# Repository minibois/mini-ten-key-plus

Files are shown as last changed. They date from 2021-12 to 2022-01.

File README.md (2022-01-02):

# mini-ten-key-plus
## Repository for the mini Ten Key Plus, a Pro Micro based numpad/macropad PCB, suitable for up to 25 MX(-like) keyswitches and a (tactile) rotary encoder.
It is recommended to download the latest release of this project: https://github.com/minibois/ten-key-plus/releases

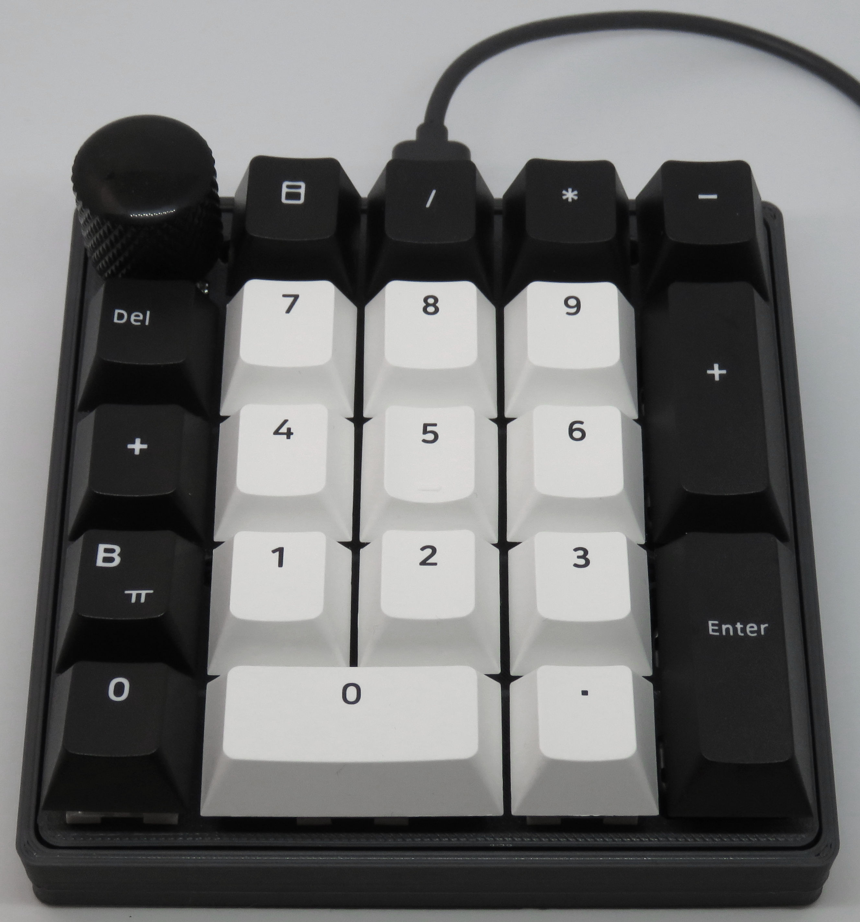
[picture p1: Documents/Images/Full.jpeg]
mini-Ten-Key-Plus-Built

 This PCB can be used using a 3D printed plate and case, also provided in this repository

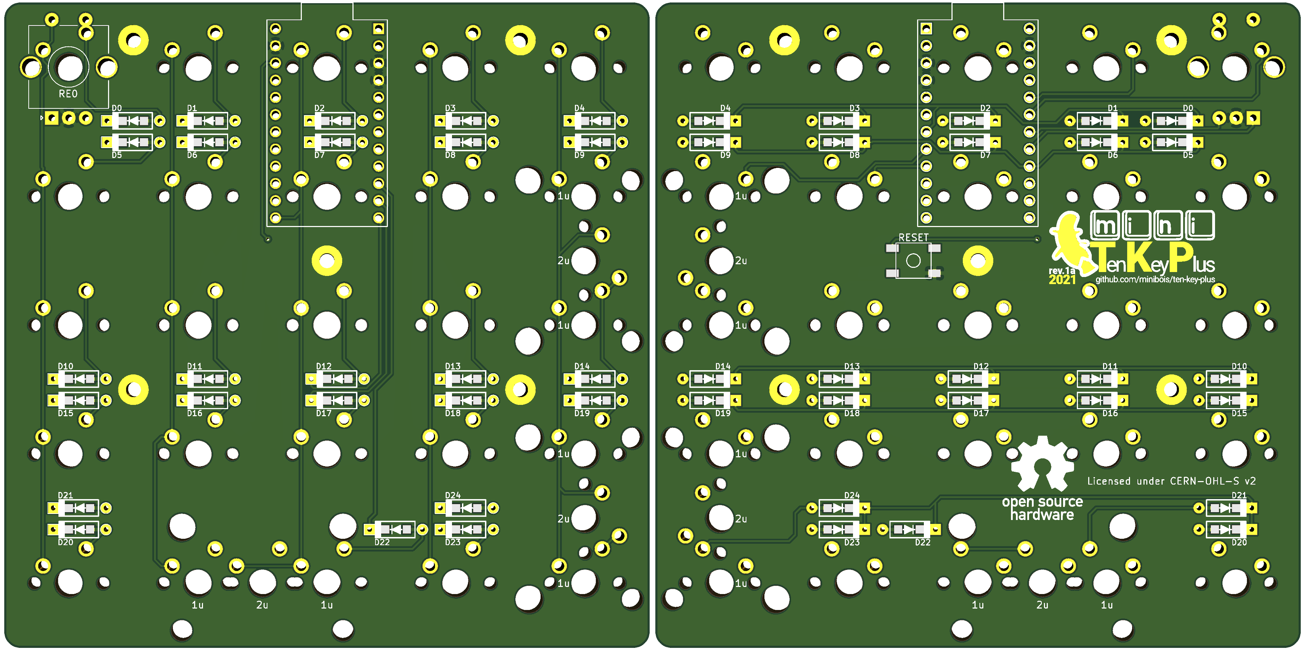
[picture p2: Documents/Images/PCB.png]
mini-Ten-Key-Plus-PCB-Render

 _Render of the front and back of the PCB respectively_

 << [License](https://github.com/minibois/ten-key-plus/tree/master/LICENSE) || [Assembly Guide](https://github.com/minibois/ten-key-plus/blob/master/Documents/Assembly%20Guide.pdf) || BOM ([Octoparts](https://octopart.com/bom-tool/pvFPXgm8)) / ([.txt](https://github.com/minibois/ten-key-plus/blob/master/Documents/BOM.txt)) / ([.xlsx](https://github.com/minibois/ten-key-plus/blob/master/Documents/BOM.xlsx)) || [Supported layouts](https://raw.githubusercontent.com/minibois/ten-key-plus/master/Documents/Layouts/layouts.png) || Schematic ([.pdf](https://github.com/minibois/ten-key-plus/blob/master/Documents/Schematic.pdf)) / ([.sch](https://github.com/minibois/ten-key-plus/blob/master/mini-ten-key-plus.sch)) || PCB ([.pdf](https://github.com/minibois/ten-key-plus/blob/master/Documents/PCB.pdf)) / ([.kicad_pcb](https://github.com/minibois/ten-key-plus/blob/master/mini-ten-key-plus.kicad_pcb)) >>

 The PCB and schematic are licensed under CERN-OHL-S v2, full license details can be found here: https://github.com/minibois/ten-key-plus/tree/master/LICENSE/LICENSE.txt.

## Libraries used in this project (most of them adapted to this project):
 * That-Canadian's KiCad_labs (for the D-SOD123_axial-dual): https://github.com/That-Canadian/KiCad_Libs
 * Type-C.Pretty: https://github.com/ai03-2725/Type-C.pretty
 * MX_Alps_Hybrid: https://github.com/ai03-2725/MX_Alps_Hybrid
 * random-keyboard-parts (for a reset switch): https://github.com/ai03-2725/random-keyboard-parts.pretty

### This PCB file and schematic is provided - as per CERN-OHL-S v2 section 6 - _without any warranty_ (implied or otherwise). https://ohwr.org/cern_ohl_s_v2.pdf
### The assembly guide is provided under the CC BY-SA 4.0, without any warranty (implied or otherwise): https://creativecommons.org/licenses/by-sa/4.0/legalcode

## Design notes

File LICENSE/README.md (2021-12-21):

# Copyright minibois 2021.

This source describes Open Hardware and is licensed under the CERN-OHL-S v2.
You may redistribute and modify this source and make products using it under the terms of the CERN-OHL-S v2 (https://ohwr.org/cern_ohl_s_v2.txt).
This source is distributed WITHOUT ANY EXPRESS OR IMPLIED WARRANTY, INCLUDING OF MERCHANTABILITY, SATISFACTORY QUALITY AND FITNESS FOR A PARTICULAR PURPOSE.
Please see the CERN-OHL-S v2 for applicable conditions.

As per CERN-OHL-S v2 section 4, should you produce hardware based on this source, you must where practicable maintain the Source Location visible on the keypad PCB or on other products you make using this source.
Source location: https://github.com/minibois/ten-key-plus
When changes have been made, please update ../Documents/CHANGES.txt accordingly.

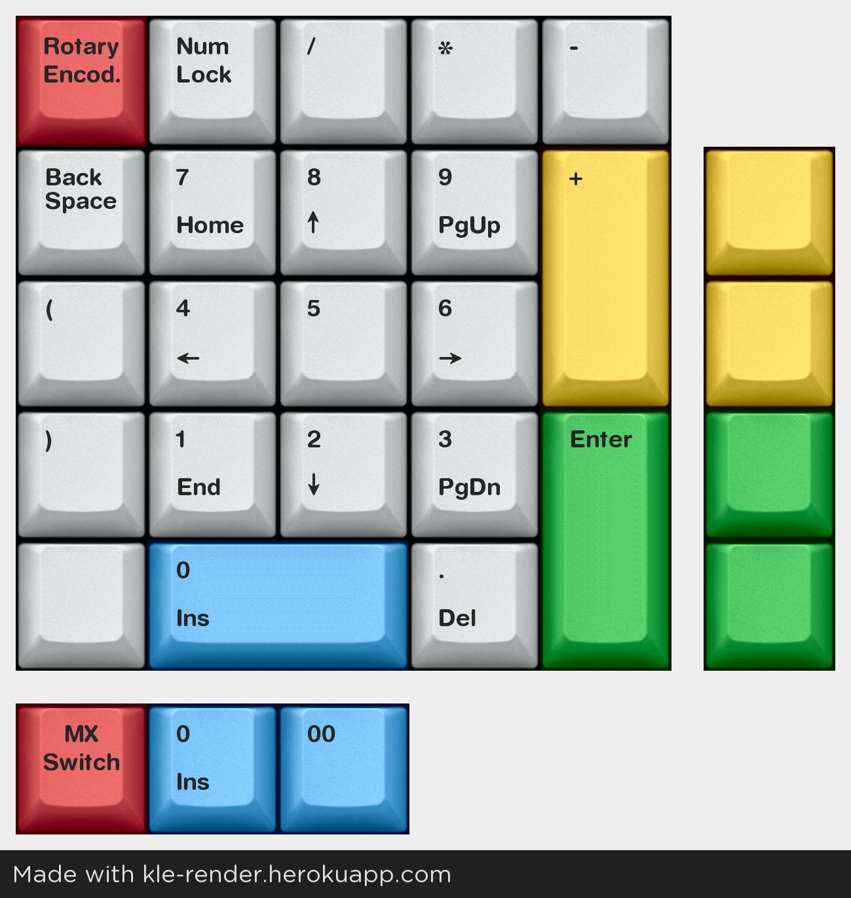
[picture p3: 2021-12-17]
Documents/Layouts/layouts.png

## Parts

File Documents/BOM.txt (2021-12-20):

Qty	Product			Description	Schematic	Notes
1	mini_Ten_Key_Plus PCB	PCB		N/A		To be purchased from your preffered PCB manufacturer
1	Arduino Pro Micro	Microcontroller	U0		Pro Micro or equivalent (i.e. Elite-C)
1	MCU Hotswap sockets	Microcontroller	N/A		(Optional) Hotswap socket for microcontroller, to allow for the removal of the MCU.
22-25	1N4148			THT Diode	D0-D24		Either this or 1N4148W
22-25	1N4148W			SMD Diode	D0-D24		Either this or 1N4148
22-25	MX Switches				MX0-MX24	MX (or MX-like) switches
1	RS187R05A2DSMTRT	Reset Switch	SW0
1	ALP-ENC-IND-000		Rotary Encoder	RE0		(Optional)
1 	Stabilizers						(Optional) Stabilizers for 2u keys
1	Lubricant						(Optional) to make the stabilizers feel better
22-25	Keycaps							A set appropriate for the chosen layout
1	USB type C cable					USB 2.0 or better
	3D printed case 					Refer to the assembly guide for additional information
	3D printed plate					Refer to the assembly guide for additional information
5	Heat Insert						M2, 3mm diameter, 3mm length heat inserts
5	Standoffs						M2, 3mm height
5	Screw							M2, 4mm height
2	Case feet						(Optional) feet to prop up the case
	Assembly tools/supplies					Refer to the assembly guide for a list of tools and supplies needed

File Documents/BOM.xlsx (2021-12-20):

Qty | Product | Description | Schematic | Notes
1 | mini_Ten_Key_Plus PCB | PCB | N/A | To be purchased from your preffered PCB manufacturer
1 | Arduino Pro Micro | Microcontroller | U0 | Pro Micro or equivalent (i.e. Elite-C)
1 | MCU Hotswap sockets | Microcontroller | N/A | (Optional) Hotswap socket for microcontroller, to allow for the removal of the MCU.
22-25 | 1N4148 | THT Diode | D0-D24 | Either this or 1N4148W
22-25 | 1N4148W | SMD Diode | D0-D24 | Either this or 1N4148
22-25 | MX Switches | MX (or MX-like) switches | MX0-MX24
1 | RS187R05A2DSMTRT | Reset Switch | SW0
1 | ALP-ENC-IND-000 | Rotary Encoder | RE0 | (Optional)
1 | Stabilizers |  | N/A | (Optional) Stabilizers for 2u keys
1 | Lubricant |  | N/A | (Optional) to make the stabilizers feel better
22-25 | Keycaps |  | N/A | A set appropriate for the chosen layout
1 | USB type C cable |  | N/A | USB 2.0 or better
 | 3D printed case |  | N/A | Refer to the assembly guide for additional information
 | 3D printed plate |  | N/A | Refer to the assembly guide for additional information
5 | Heat Insert |  | N/A | M2, 3mm diameter, 3mm length heat inserts
5 | Standoffs |  | N/A | M2, 3mm height
5 | Screw |  | N/A | M2, 4mm height
2 | Case feet |  | N/A | (Optional) feet to prop up the case
 | Assembly tools/supplies |  | N/A | Refer to the assembly guide for a list of tools and supplies needed

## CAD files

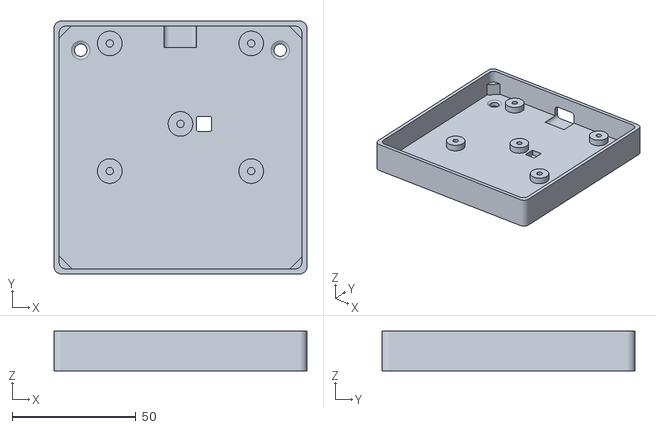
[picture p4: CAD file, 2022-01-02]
Enclosure/Case/Model.stl
102.2 x 102.2 x 16.0

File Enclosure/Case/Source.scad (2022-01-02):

/* Case */
difference() 
{
    /* Main plane */    
    color([0.5,0.5,0.5]) minkowski(){
        translate([0,0,-2])
        cube([96.25,96.25,16]);
        cylinder($fn=30,r=3, h=0.05);
    }
    
    /* Inner hole cutout */        
    translate([2,2,0.99])
    minkowski(){
        cube([92.25,92.25,16]);
        cylinder($fn=30,r=3, h=0.05);
    }
        
    translate([0.5,0.5,0])
    {
        /* Screw holes */
        /* Top */
        translate([19.05,89.69,0])
        {
            HeatInsertHole();
        }
        translate([76.20,89.69,0])
        {
            HeatInsertHole();
        }
        /* Center */
        translate([47.62,57.15,0])
        {
            HeatInsertHole();
        }
        /* Bottom */
        translate([19.05,38.10,0])
        {
            HeatInsertHole();
        }
        translate([76.20,38.10,0])
        {
            HeatInsertHole();
        }
        
        /* RESET button */
        minkowski(){
            translate([54.65,54.65,-5])
            color([1,1,1]) cube([5,5,10]);
            cylinder($fn=30,r=0.5, h=0.05);
        }
        
        /* USB port/header cutout */
        rotate([90,0,0]){
            minkowski(){
                translate([43,1,-100])
                color([1,1,1]) cube([9,4,12]);
                cylinder($fn=30,r=2, h=0.05);
            }
        }
        
        /* Micro USB cable cutout */
        rotate([90,0,0]){
            minkowski(){
                translate([43,1,-100])
                color([1,1,1]) cube([9,4,12]);
                cylinder($fn=30,r=2, h=0.05);
            }
        }
    }
    
    /* Screw on feet holes */
    /* Left */
    translate([7.8,87.45,0])
    {
        CornerScrew();  
    }
    /* Right */
    translate([88.45,87.45,0])
    {
        CornerScrew();
    }
}

/* Corner stands */
intersection()
{
    /* Inner hole cutout */        
    translate([1.5,1.5,1])
    color([0.5,0.5,0.5])  minkowski(){
        cube([93.25,93.25,16]);
        cylinder($fn=30,r=3, h=0.05);
    }
    /* Stands */
    translate([0.5,0.5,0])
    {
        /* Bottom Left */
        translate([-5,1,0])
        rotate([0,0,-45]) color([1,1,1]) cube([8,4.5,7.4]);
        /* Bottom Right */
        translate([94.6,-5,0])
        rotate([0,0,45]) color([1,1,1]) cube([8,4.5,7.4]);

        /* Top Left */
        translate([-4,93.7,0])
        rotate([0,0,-45]) color([1,1,1]) cube([3.2,8,7.4]);
        /* Top Right */
        translate([96.7,91.7,0])
        rotate([0,0,45]) color([1,1,1]) cube([3.2,8,7.4]);
    }
}

/* Heat insert hole posts */
translate([0.5,0.5,0])
{
    /* Screw holes */
    /* Top */
    translate([19.05,89.69,0])
    {
        HeatInsertHoleRiser();
    }
    translate([76.20,89.69,0])
    {
        HeatInsertHoleRiser();
    }
    /* Center */
    translate([47.62,57.15,0])
    {
        HeatInsertHoleRiser();
    }
    /* Bottom */
    translate([19.05,38.10,0])
    {
        HeatInsertHoleRiser();
    }
    translate([76.20,38.10,0])
    {
        HeatInsertHoleRiser();
    }
}

/* Different modules */
/* Heat insert holes */
module HeatInsertHole()
{
    translate([0,0,2.16])
    {
        color([1,1,1]) cylinder($fn=30,h=4.6,d=3, center=true);
    }
}

module HeatInsertHoleRiser()
{
    difference()
    {
        translate([0,0,2.16])
        {
            color([1,1,1]) cylinder($fn=30,h=4.5,d=10, center=true);
        }
        HeatInsertHole();
    }
}
module CornerScrew()
{
    cylinder($fn=30,h=10,d=5, center=true);
    translate([0,0,-1.29])
    {
        cylinder($fn=30,h=2.3, r1=0, r2 = 3.8, center = false);
    }
    /* Extra depth cylinder */
    translate([0,0,6])
    {
        cylinder($fn=30,h=10,d=7.6, center=true);
    }
}

module CornerScrewRiser()
{
    difference()
    {
        translate([0,0,2])
        {
            color([1,1,1]) cylinder($fn=30,h=4.82,d=12, center=true);
        }
        CornerScrew();
    }
}

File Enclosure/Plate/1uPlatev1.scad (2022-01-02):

/* 1u Plate */
difference() {
    translate([2,2,0])
    color([0.5,0.5,0.5])  minkowski(){
        cube([91.25,91.25,2.5]);
        cylinder($fn=30,r=3, h=0.05);
    }
    
    /* Screw holes */
    /* Top */
    translate([19.05,89.69,0])
            ScrewHole();
    translate([76.20,89.69,0])
            ScrewHole();
    /* Center */
    translate([47.62,57.15,0])
            ScrewHole();
    /* Bottom */
    translate([19.05,38.10,0])
            ScrewHoleBig();
    translate([76.20,38.10,0])
            ScrewHoleBig();
    
    
    /* Switch cutouts */
    translate([2.5,2.5,-1])
    {
        /* Row 0 */
        translate([0,0,0])
        {
            cube([14,14,8]);
            
            translate([19.05,0,0])
            cube([14,14,8]);
            
            translate([38.1,0,0])
            cube([14,14,8]);
            
            translate([57.15,0,0])
            cube([14,14,8]);
            
            translate([76.2,0,0])
            cube([14,14,8]);
        }
        
        /* Row 1 */
        translate([0,19.05,0])
        {
            cube([14,14,8]);
            
            translate([19.05,0,0])
            cube([14,14,8]);
            
            translate([38.1,0,0])
            cube([14,14,8]);
            
            translate([57.15,0,0])
            cube([14,14,8]);
            
            translate([76.2,0,0])
            cube([14,14,8]);
        }
        
        /* Row 2 */
        translate([0,38.1,0])
        {
            cube([14,14,8]);
            
            translate([19.05,0,0])
            cube([14,14,8]);
            
            translate([38.1,0,0])
            cube([14,14,8]);
            
            translate([57.15,0,0])
            cube([14,14,8]);
            
            translate([76.2,0,0])
            cube([14,14,8]);
        }
        
        /* Row 3 */
        translate([0,57.15,0])
        {
            cube([14,14,8]);
            
            translate([19.05,0,0])
            cube([14,14,8]);
            
            translate([38.1,0,0])
            cube([14,14,8]);
            
            translate([57.15,0,0])
            cube([14,14,8]);
            
            translate([76.2,0,0])
            cube([14,14,8]);
        }
        
        /* Row 4 */
        translate([0,76.2,0])
        {
            cube([14,14,8]);
            
            translate([19.05,0,0])
            cube([14,14,8]);
            
            translate([38.1,0,0])
            cube([14,14,8]);
            
            translate([57.15,0,0])
            cube([14,14,8]);
            
            translate([76.2,0,0])
            cube([14,14,8]);
        }
    }
}

module ScrewHole()
{
    color([1,1,1]) cylinder($fn=30,h=15,d=4.19, center=true);
}
module ScrewHoleBig()
{
    color([1,1,1]) cylinder($fn=30,h=15,d=4.7, center=true);
}

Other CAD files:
Enclosure/Plate/1uPlatev2.scad
Enclosure/Plate/2uPlate.scad

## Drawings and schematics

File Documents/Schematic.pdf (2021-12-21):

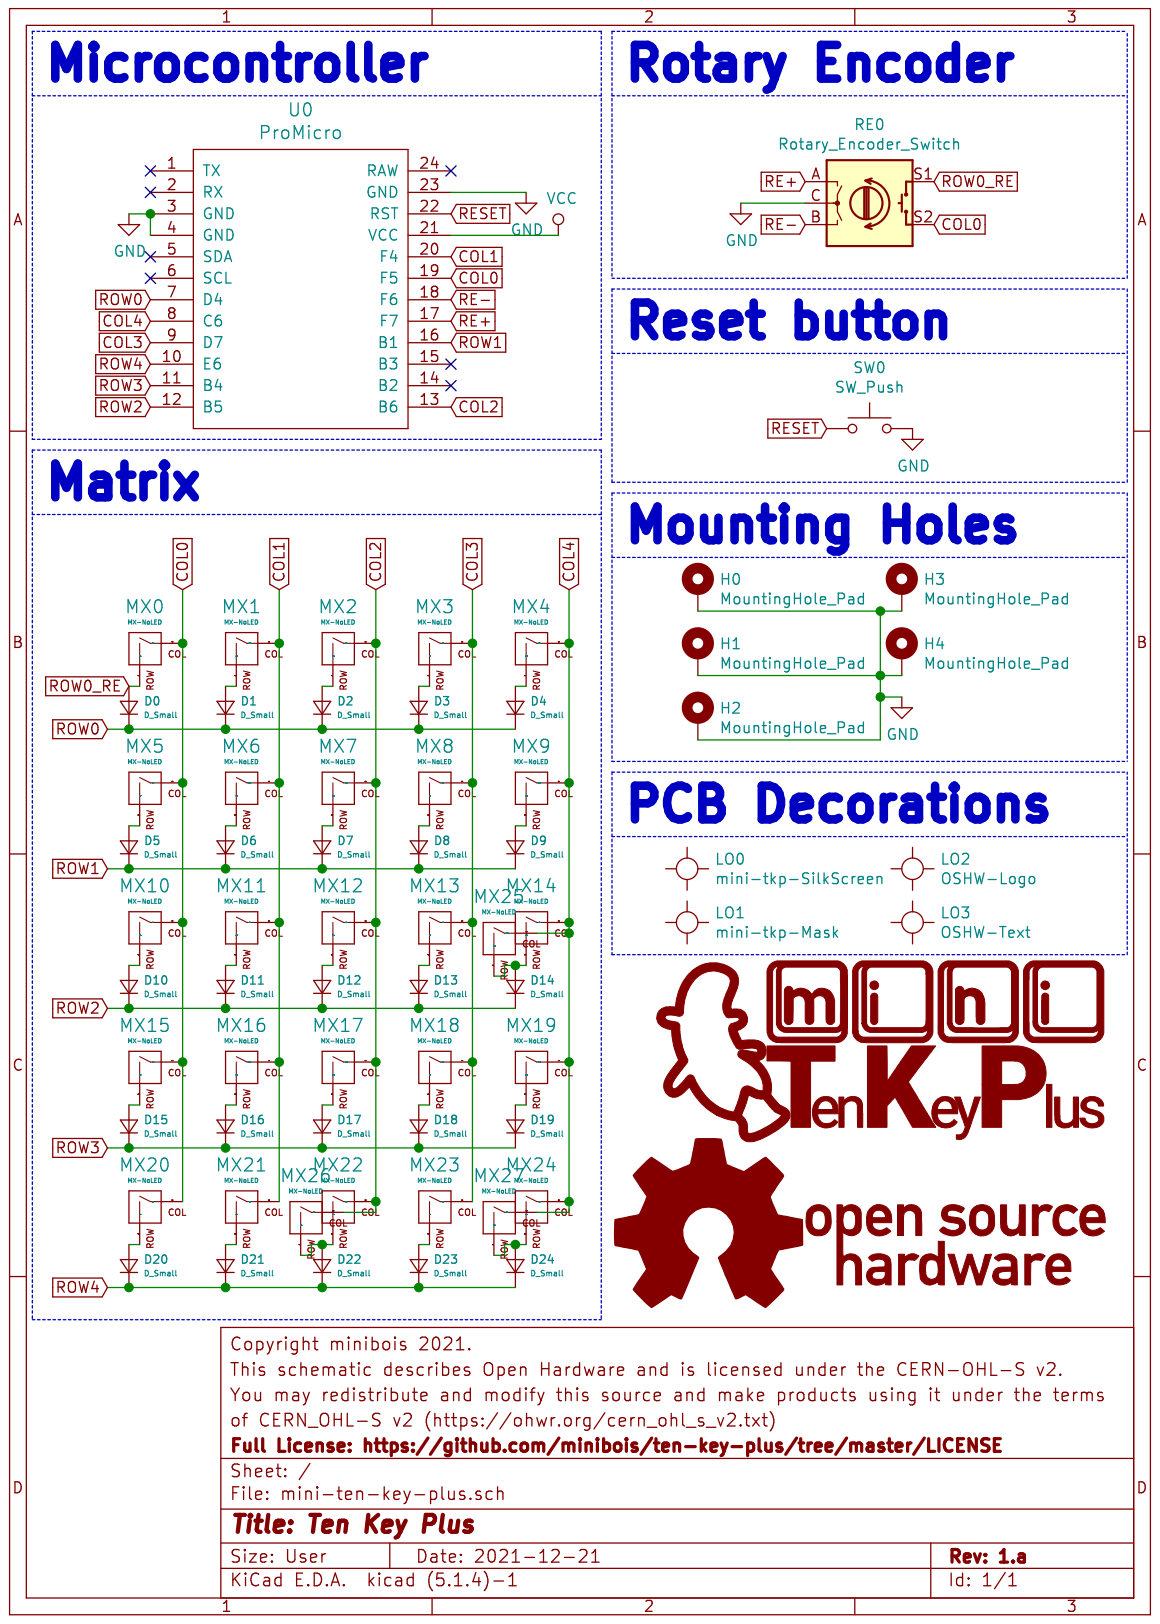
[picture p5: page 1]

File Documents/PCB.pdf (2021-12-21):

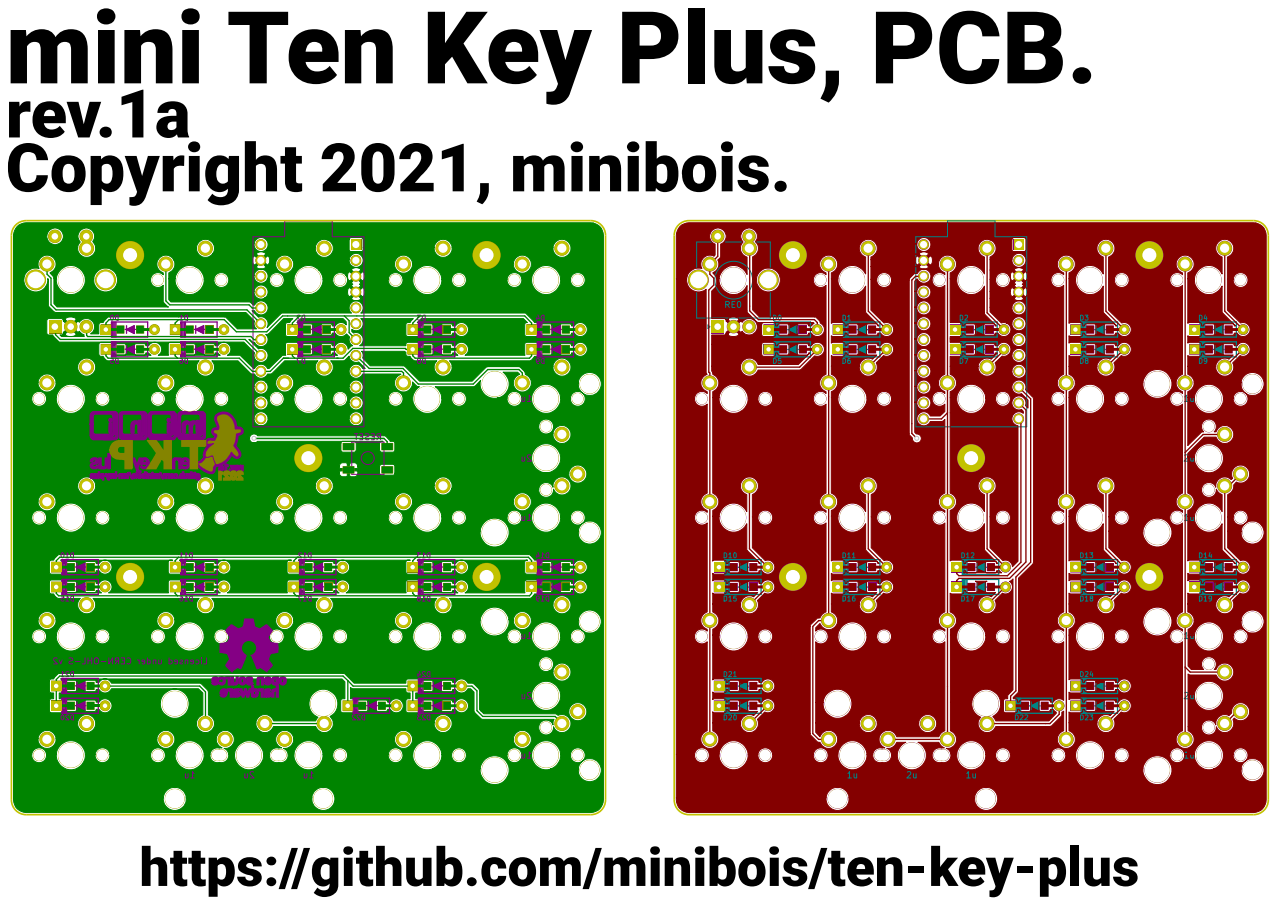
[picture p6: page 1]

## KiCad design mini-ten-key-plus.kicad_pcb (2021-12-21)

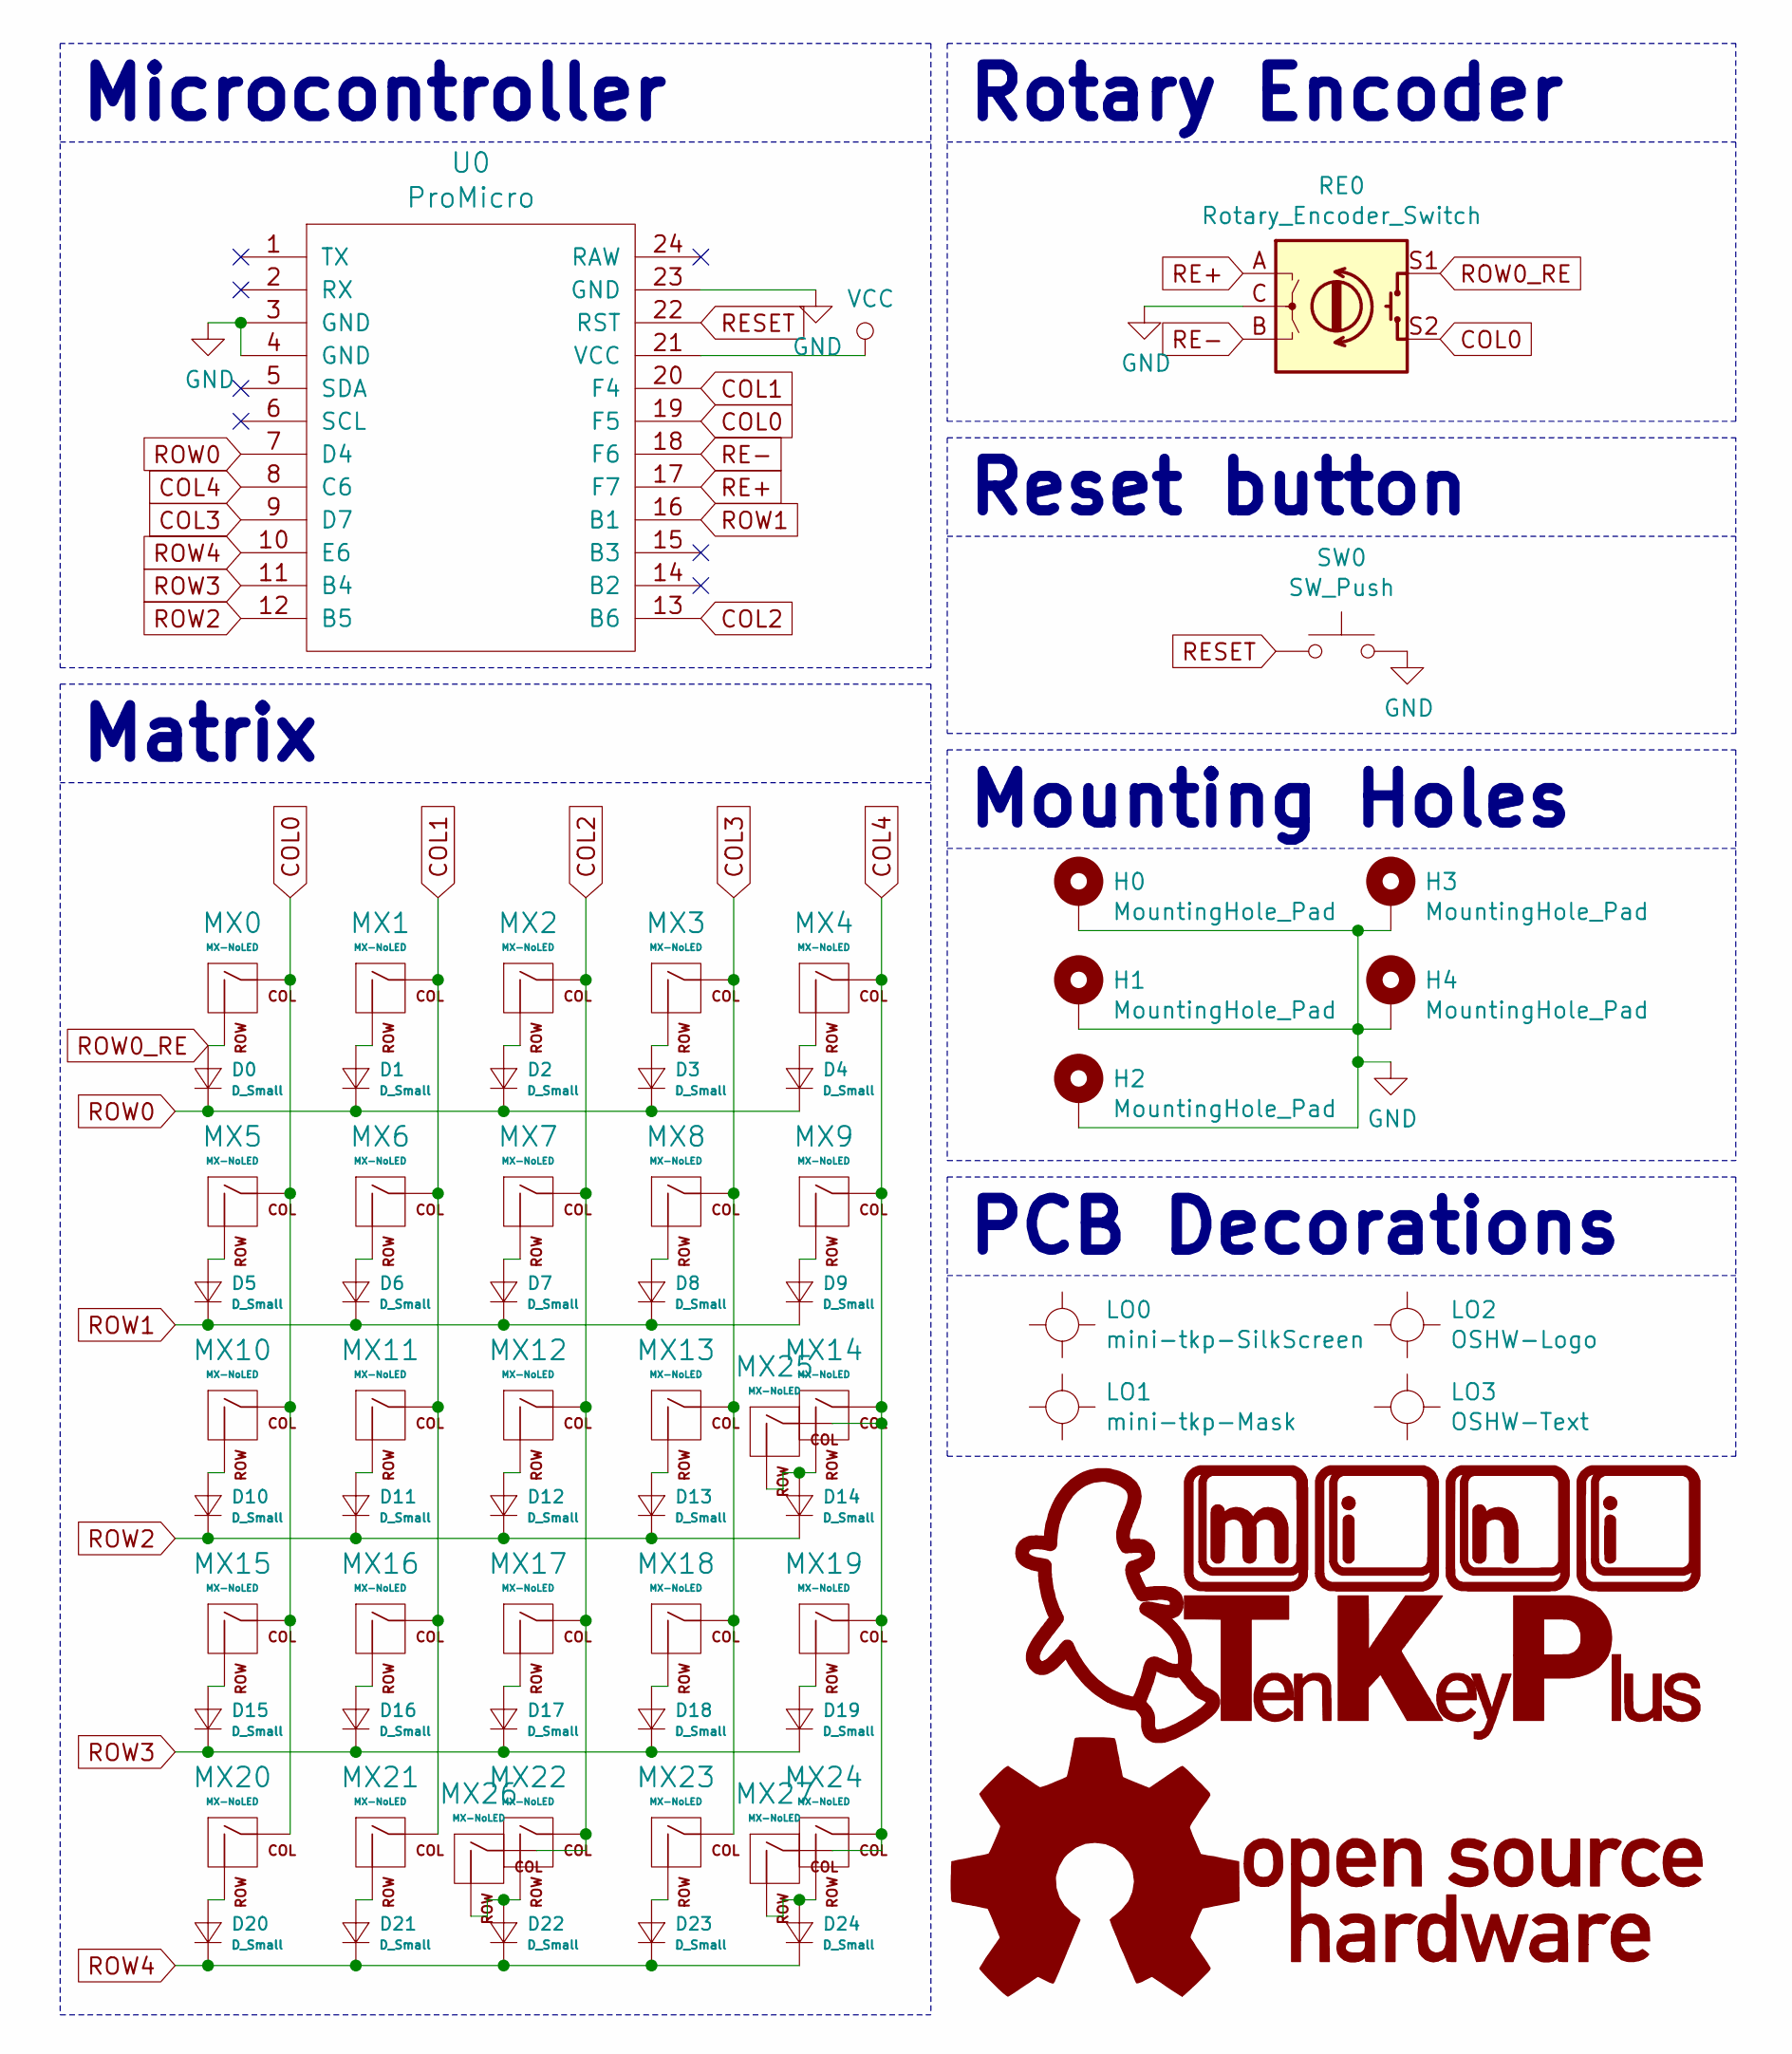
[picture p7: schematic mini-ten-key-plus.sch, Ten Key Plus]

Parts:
D0, D1, D2, D3, D4, D5, D6, D7, D8, D9, D10, D11, D12, D13, D14, D15, D16, D17, D18, D19, D20, D21, D22, D23, D24: D_Small; D_SOD123_axial-dual
H0, H1, H2, H3, H4: MountingHole_Pad; MountingHole_2.2mm_M2_Pad_tweaked
LO0: mini-tkp-SilkScreen; mini-TKP-BSilk
LO1: mini-tkp-Mask; mini-TKP-BMask
LO2: OSHW-Logo
LO3: OSHW-Text
MX0, MX1, MX2, MX3, MX4, MX5, MX6, MX7, MX8, MX9, MX10, MX11, MX12, MX13, MX14, MX15, MX16, MX17, MX18, MX19, MX20, MX21, MX22, MX23, MX24: MX-NoLED; MXOnly-1U-NoLED_tweak
MX25, MX27: MX-NoLED; MXOnly-2U-NoLED_tweak
MX26: MX-NoLED; MXOnly-2U-NoLED_FLIPPED_tweak
RE0: Rotary_Encoder_Switch; RotaryEncoder_Alps_EC11E-Switch-Vertical-EDIT
SW0: SW_Push; SKQG-1155865
U0: ProMicro

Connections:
COL0: MX0.1 (COL), MX5.1 (COL), MX10.1 (COL), MX15.1 (COL), MX20.1 (COL), RE0.S2, U0.19 (F5)
COL1: MX1.1 (COL), MX6.1 (COL), MX11.1 (COL), MX16.1 (COL), MX21.1 (COL), U0.20 (F4)
COL2: MX2.1 (COL), MX7.1 (COL), MX12.1 (COL), MX17.1 (COL), MX22.1 (COL), MX26.1 (COL), U0.13 (B6)
COL3: MX3.1 (COL), MX8.1 (COL), MX13.1 (COL), MX18.1 (COL), MX23.1 (COL), U0.9 (D7)
COL4: MX4.1 (COL), MX9.1 (COL), MX14.1 (COL), MX19.1 (COL), MX24.1 (COL), MX25.1 (COL), MX27.1 (COL), U0.8 (C6)
GND: H0.1, H1.1, H2.1, H3.1, H4.1, RE0.C, SW0.2, U0.3 (GND), U0.4 (GND), U0.23 (GND); also elsewhere on the board
unnamed: D1.2 (A), MX1.2 (ROW)
unnamed: D2.2 (A), MX2.2 (ROW)
unnamed: D3.2 (A), MX3.2 (ROW)
unnamed: D4.2 (A), MX4.2 (ROW)
unnamed: D5.2 (A), MX5.2 (ROW)
unnamed: D6.2 (A), MX6.2 (ROW)
unnamed: D7.2 (A), MX7.2 (ROW)
unnamed: D8.2 (A), MX8.2 (ROW)
unnamed: D9.2 (A), MX9.2 (ROW)
unnamed: D10.2 (A), MX10.2 (ROW)
unnamed: D11.2 (A), MX11.2 (ROW)
unnamed: D12.2 (A), MX12.2 (ROW)
unnamed: D13.2 (A), MX13.2 (ROW)
unnamed: D14.2 (A), MX14.2 (ROW), MX25.2 (ROW)
unnamed: D15.2 (A), MX15.2 (ROW)
unnamed: D16.2 (A), MX16.2 (ROW)
unnamed: D17.2 (A), MX17.2 (ROW)
unnamed: D18.2 (A), MX18.2 (ROW)
unnamed: D19.2 (A), MX19.2 (ROW)
unnamed: D20.2 (A), MX20.2 (ROW)
unnamed: D21.2 (A), MX21.2 (ROW)
unnamed: D22.2 (A), MX22.2 (ROW), MX26.2 (ROW)
unnamed: D23.2 (A), MX23.2 (ROW)
unnamed: D24.2 (A), MX24.2 (ROW), MX27.2 (ROW)
RE+: RE0.A, U0.17 (F7)
RE-: RE0.B, U0.18 (F6)
RESET: SW0.1, U0.22 (RST); also elsewhere on the board
ROW0: D0.1 (K), D1.1 (K), D2.1 (K), D3.1 (K), D4.1 (K), U0.7 (D4)
ROW0_RE: D0.2 (A), MX0.2 (ROW), RE0.S1
ROW1: D5.1 (K), D6.1 (K), D7.1 (K), D8.1 (K), D9.1 (K), U0.16 (B1)
ROW2: D10.1 (K), D11.1 (K), D12.1 (K), D13.1 (K), D14.1 (K), U0.12 (B5)
ROW3: D15.1 (K), D16.1 (K), D17.1 (K), D18.1 (K), D19.1 (K), U0.11 (B4)
ROW4: D20.1 (K), D21.1 (K), D22.1 (K), D23.1 (K), D24.1 (K), U0.10 (E6)
VCC: U0.21 (VCC)

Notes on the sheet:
Matrix
Microcontroller
Reset button
Mounting Holes
PCB Decorations
Rotary Encoder

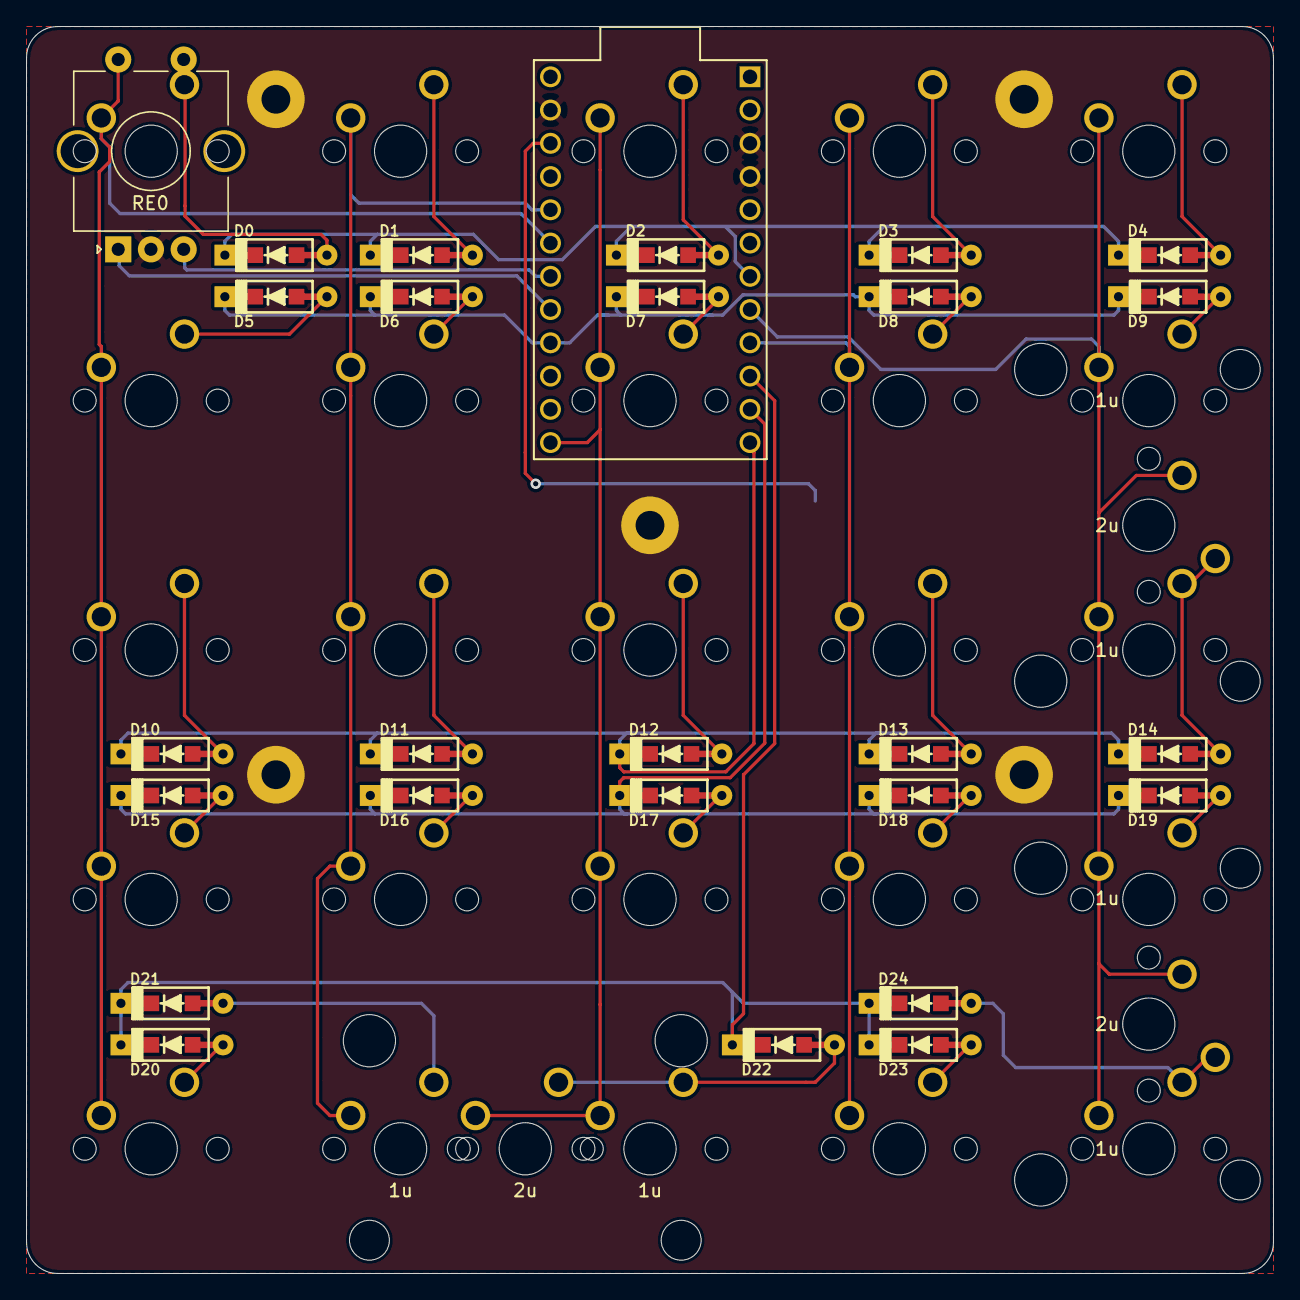
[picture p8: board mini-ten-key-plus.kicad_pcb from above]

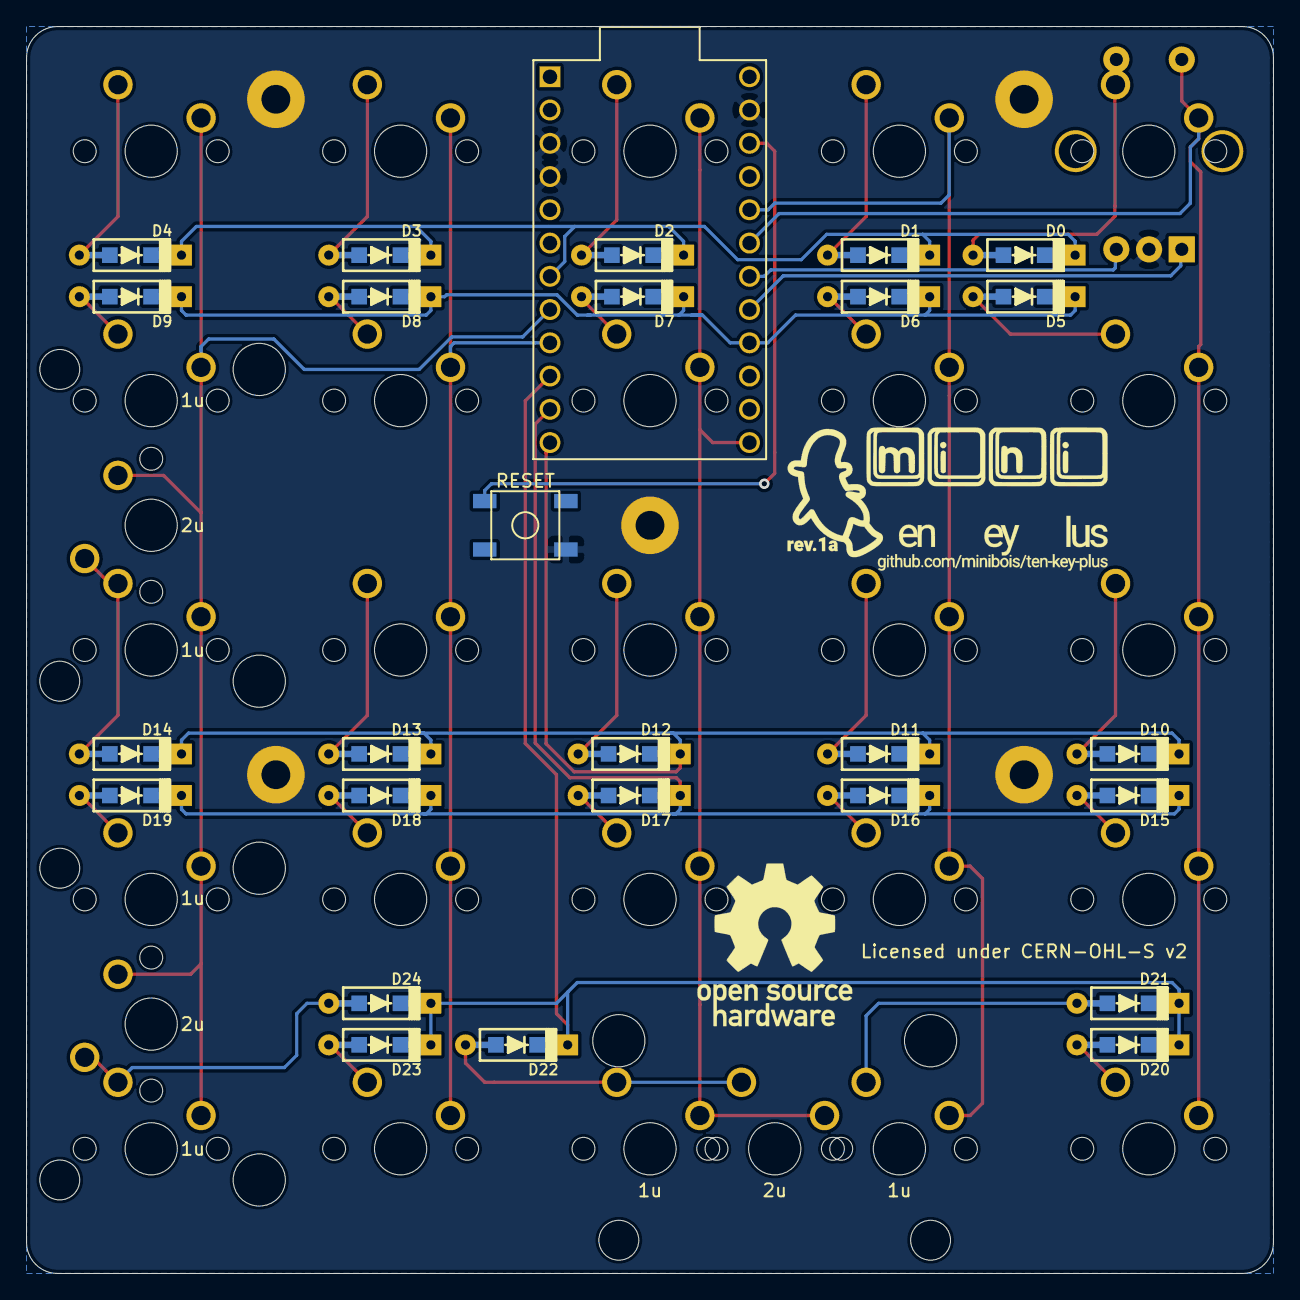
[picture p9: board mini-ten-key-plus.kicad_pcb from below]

Board: 2 copper layers, 95.2 x 95.2 mm, 65 parts (3 on the bottom side), 39 nets.

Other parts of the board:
RESET: SW_Push; SKQG-1155865

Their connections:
GND: RESET.2; also elsewhere on the board
RESET: RESET.1; also elsewhere on the board

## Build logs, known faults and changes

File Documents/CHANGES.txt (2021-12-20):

2021-10-20: CHANGES.txt made.
This file can be used to document any change(s) made to this open source project, as per 3.1.2 of the CERN-OHL-S v2 User Guide.
Please use the YYYY-MM-DD date format (ISO 8601) and list the modification(s) made.

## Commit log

2021-10-20 Created project.
    [mini-ten-key-plus.kicad_pcb, mini-ten-key-plus.sch]
2021-10-20 Added libraries via KiCAD
2021-10-20 Added Pro Micro library to KiCAD
2021-10-20 Added random keyboard parts, for reset switch
2021-10-21 Laid out PCB, ran most traces (sans col/row to MCU)
    [mini-ten-key-plus.kicad_pcb]
2021-10-22 Did practice col/row wiring
    [mini-ten-key-plus.kicad_pcb, mini-ten-key-plus.sch]
2021-10-22 Ran first versions of row/col pins
    [mini-ten-key-plus.kicad_pcb]
2021-10-22 Rotated Pro Micro around
    [mini-ten-key-plus.kicad_pcb]
2021-10-22 Flipped Pro Micro and redid rows/cols
    [mini-ten-key-plus.kicad_pcb, mini-ten-key-plus.sch]
2021-10-24 Trying to remove row 4 trace
    [mini-ten-key-plus.kicad_pcb]
2021-10-28 General routing
    [mini-ten-key-plus.kicad_pcb, mini-ten-key-plus.sch]
2021-10-29 Added extra column of keys on the left side
    [mini-ten-key-plus.kicad_pcb, mini-ten-key-plus.sch]
2021-11-01 Cleaned up schematic
    [mini-ten-key-plus.sch]
2021-11-02 Added rotary encoder
    [mini-ten-key-plus.kicad_pcb, mini-ten-key-plus.sch]
2021-11-10 Added TKP logo, restructured schematic
    [mini-ten-key-plus.kicad_pcb, mini-ten-key-plus.sch]
2021-11-10 Made gerber files
    [mini-ten-key-plus-B_Cu.gbl, mini-ten-key-plus-B_Mask.gbs, mini-ten-key-plus-B_SilkS.gbo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]
2021-12-17 Added layout image and general edits
    [mini-ten-key-plus.sch]
2021-12-20 Added BOM.txt and BOM.xlsx
    [BOM.xlsx]
2021-12-20 Updated BOM.txt
2021-12-21 Added LICENSE
    [mini-ten-key-plus.sch]
2021-12-21 Added additional info to PCB/Schematic and added PCB/Schematic PDF
    [mini-ten-key-plus.kicad_pcb, mini-ten-key-plus.sch]
2022-01-02 Added case, plate, images and updated README.md
    [1uPlatev1.scad, 1uPlatev2.scad, 2uPlate.scad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]

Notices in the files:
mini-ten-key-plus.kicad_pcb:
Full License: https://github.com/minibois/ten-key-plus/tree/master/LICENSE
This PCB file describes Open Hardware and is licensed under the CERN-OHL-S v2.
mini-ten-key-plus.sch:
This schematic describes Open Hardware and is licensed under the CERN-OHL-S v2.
